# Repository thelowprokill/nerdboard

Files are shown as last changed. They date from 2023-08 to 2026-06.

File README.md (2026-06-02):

# nerdboard

This is my take on a split ergonomic keyboard.
I will add documentation to buid it here soon.

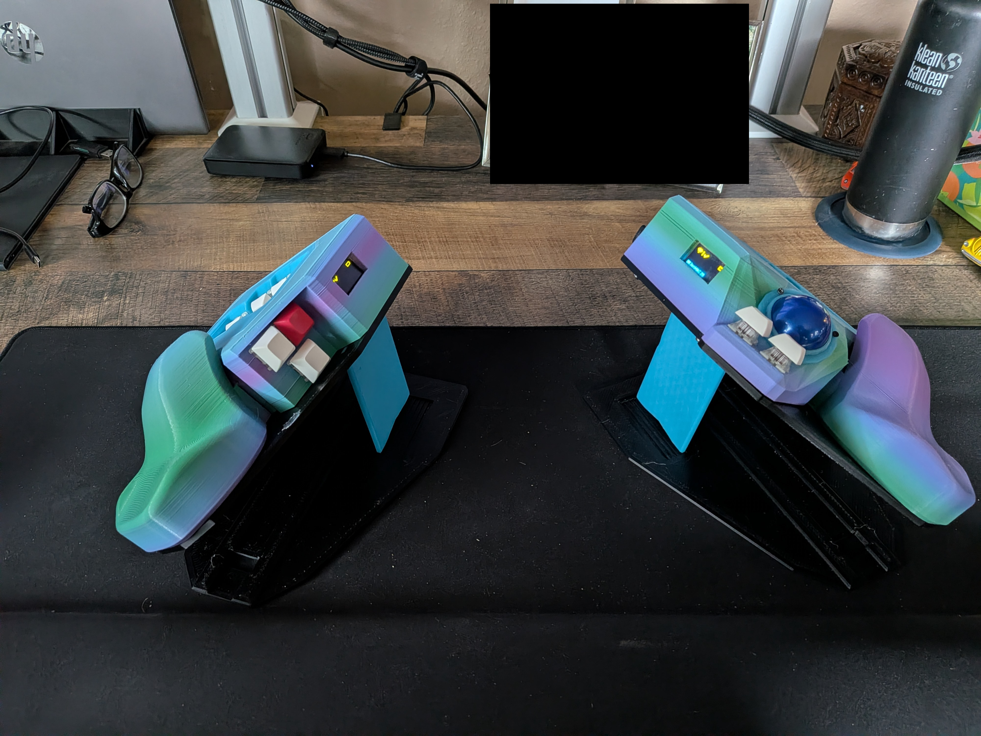
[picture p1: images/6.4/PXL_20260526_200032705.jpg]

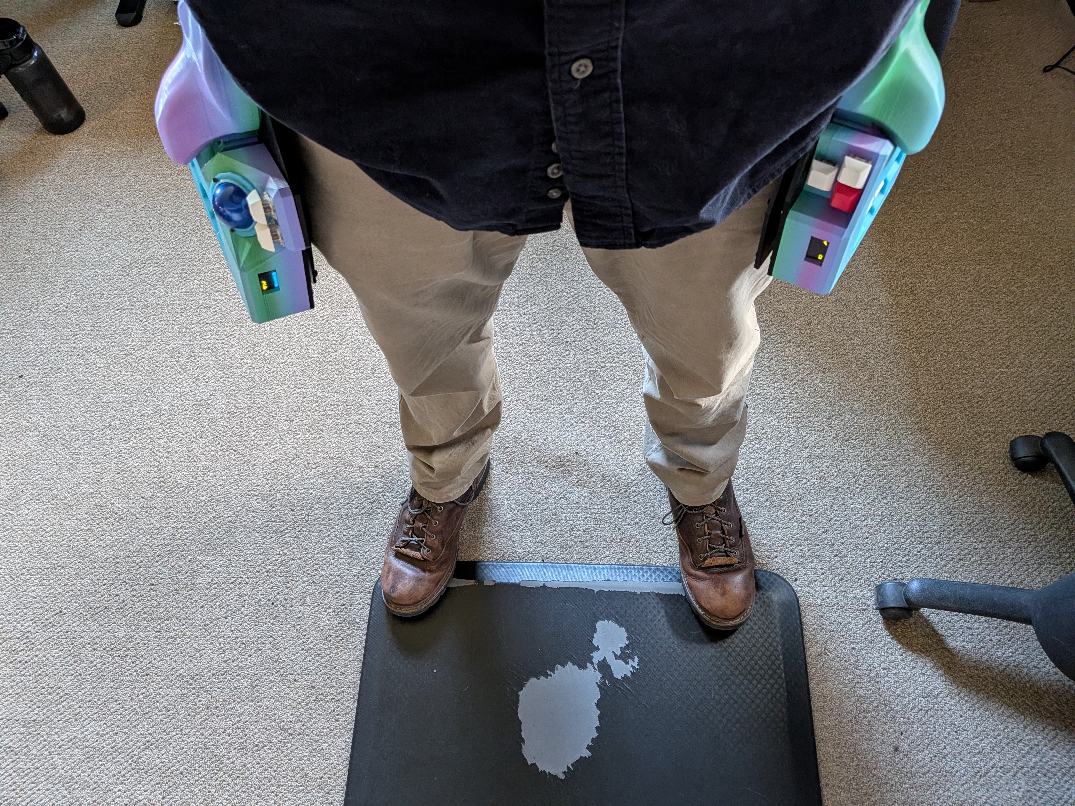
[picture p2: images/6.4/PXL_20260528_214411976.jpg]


# Versions
## 1.0
This version is not my own creation. 
I found it here on [GitHub](https://github.com/Schievel1/dactyl_manuform_r_track).
This is where I started from.

## 2.0
This was my first creation.
I reduced the number of keys from 62 to 46 and tented to make it more ergonomic.
I added holes for the USB cables and reset buttons.
There was a major error on this one where I mirrored the left side to make the right. This made non of the hot swap sockets work.
This one is the most difficult to make.

## 3.0
This is my second creation.
I do not recomend this one.
It is too big.
I didn't realize until I printed it.

## 4.0
This is my third creation.
I do not recomend this one.
I never finished designing it.
Part way through I abandoned it to pursue what became 5.0.

## 5.0
This is my fourth creation.
This one is fine. 
This was the one that reduced the number of keys to 34.
I didn't know what to do with the thumb clusters so they got placed to far away.

## 6.0 
This is my fifth creation.
I really like this one. 
This one reduced the number of keys to 29.
I currently use this one daily at work.
The 29 keys make it so there is no doubt of what key you are using because each finger has a maximum of 3 keys.

### 6.2 
Stability improvement over 6.0.
The palm rest was integrated into the chassis with a slot to improve regitity. 

### 6.3
Comfortability improvement over 6.2
The top part of the palm rest was actually important for comfort and was readded.
Changed the screen to a wider model.

### 6.4 2026-05-25
Switched to wireless keyboard. https://github.com/thelowprokill/zmk-config
Added a removeable keywell to make it easier to assemble and not have doors on the front and rear.
Since it is now wireless there is now a belt hook so the keyboard can be hung from my belt.
I have now been using version 6.something for coming on three years I have been loving it.

## 7 
This is a seperate design for a friend it uses a more standard layout.

## 8
This is a prototype.

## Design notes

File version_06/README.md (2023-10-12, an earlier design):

# Version 6

## Introduction
This is the sixth version of the project and first to de shared with others.
This is a 29 key split keyboard with integrated trackball.

## Hardware
29 diodes
29 switches
29 hot swap sockets
29 keycaps
2  arduino pro micros
2  female usb cables
1  usb c female to micro usb adapter
6  m2x8 screws
14 m3x6 screws
2  m2 thraded inserts
14 m3 thraded inserts
1  PMW 3360 sensor
1  34mm trackball
1  usb c male to usb c male cable
1  usb c male to computer
   jumper cables

## Build
### Print
Print all the parts.
1x left
1x right
1x small_parts

either
1x upper_plate_l
1x upper_plate_r
1x lower_plate_l
1x lower_plate_r
2x kickstand
for the tented version
or
2x plate
for the non-tented version

all the small parts print together.

Remove the supports

### Post proccessing
sand and paint as desired (optional, but recommended)
Install heat inserts into the cases and palm rests.

### Assembly
Diodes:
Solder diodes to the hot swap sockets not the polarity.
One diode per socket.
I try to make the diodes all on the same side of the column.
For one of the rows it will be on the other side.

Sockets:
Insert a socket into each hole in the keyboard.
I recomend using a switch to help hold the socket in place.

Rows:
Start at one end and solder the tail of that diode to the tail of the next diode.
This needs to be done after the diode not before.

Columns:
Use a jumper cable.
Cut off one side.
Use wire strippers to cut the shielding near the uncut side of the jumper cable.
Hold the cut up to one of the sockets I start at the top row.
Mark where it meets the next socket.
Cut the shielding there.
When you get to all the sockets in that column pull the shielding away to reveal about 5mm of the wire underneeth.
Cut the extra wire.
Cut the other side of the jumper cable.
Tin all the joints with the soldering iron.
Solder each wire to the sockets.

USB C link between keyboard halves:
Cut the usb c female cable.
Solder a jumper to VCC(red), GND(black), and Data +-(green white).
To clerify I soldered green and white together to the third jumer.

Insert the usb c female side into the prited case.
I use the hole that is closest to the other side.

USB link from keyboard to computer:
Insert the usb c to micro usb adapter into the other hole in the case.

OLED:
Verify the OLED is working by connecting to the pro micro and plugging the pro micro into a computer.
Remove the film frm the OLED screen.
Attach 4 jumper cables to the OLED note which one goes where.
Gently place the OLED in the hole in the right side of the keyboard.
Hot glue in place.

Pro Micros:
Flash the firmware on the pro micro.
Go to QMK for instructions.
Solder header pins to the pro micro.

Hot glue the pro micro to the table like stand. (Optional but recommended)
Plug in the pro micro to the adapter in the case.
Run wires for the rows or columns that go to the other side of the pro micro accross the keyboard. (Optional but recommended)
Hot glue the four corners of the table.
Place the pro micro table in the case stadleing the wires lain across the keyboard. (It is hard to get them under once the pro micro is glued down)

Matrix:
solder one jumper to each row and one to each column.
Connect to the pro micro using the wiring diagram.

Mouse sensor:
Solder the headers onto the PMW 3360 sensor.
Use two m2x8 screws to attach the sensor to the case.
Connect to the pro micro using the wiring diagram.

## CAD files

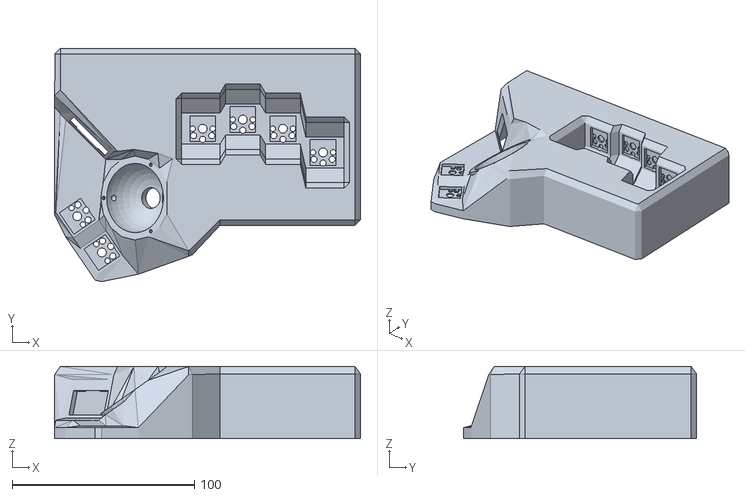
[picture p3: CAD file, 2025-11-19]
lp_01/lp_01_right.stl
167.7 x 127.8 x 39.5

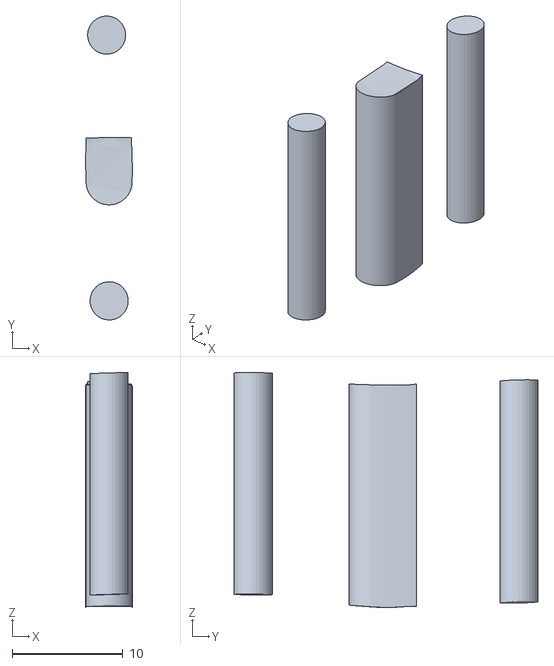
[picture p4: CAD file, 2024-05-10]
parts/sensor_negative.stl
4.21 x 27.5 x 21.2

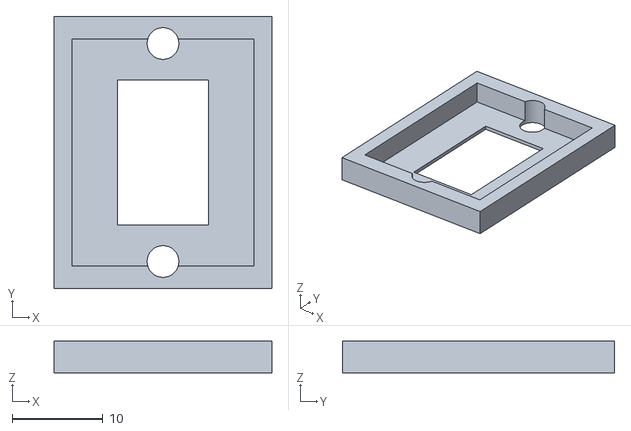
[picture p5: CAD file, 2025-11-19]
trackball_test/trackball_v3_standoff_0.5mm.stl
24.0 x 30.0 x 3.50

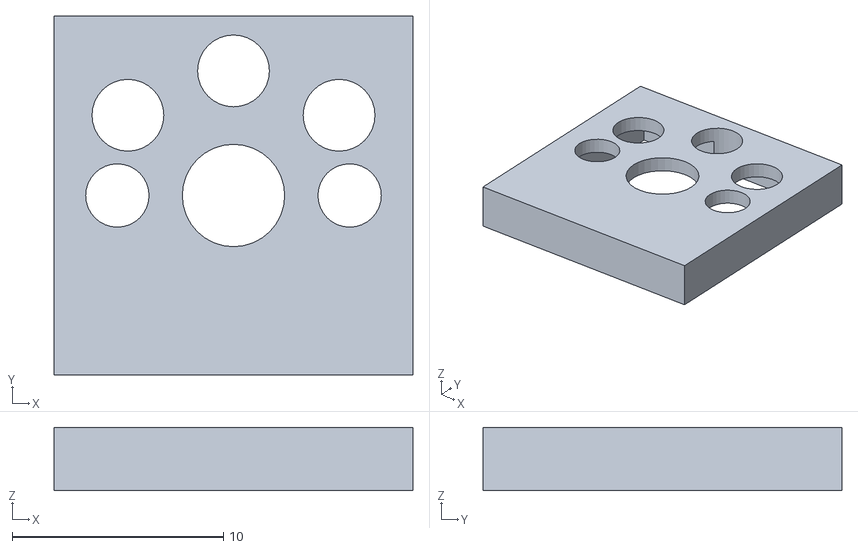
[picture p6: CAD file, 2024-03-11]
lp_01/lp_hotswap.stl
17.0 x 17.0 x 3.00

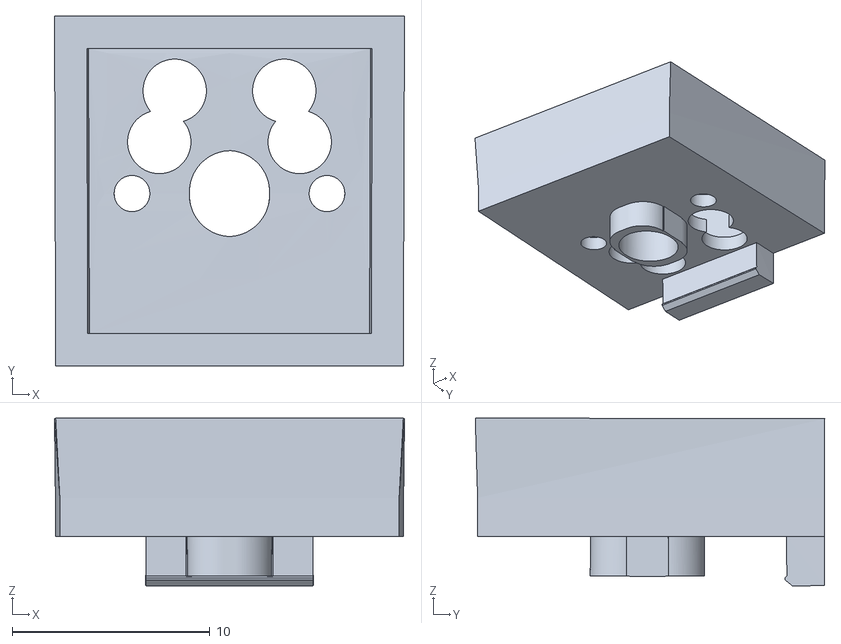
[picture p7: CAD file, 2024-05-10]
parts/hot_swap_socket_reversable_v2_test.stl
17.7 x 17.7 x 8.48

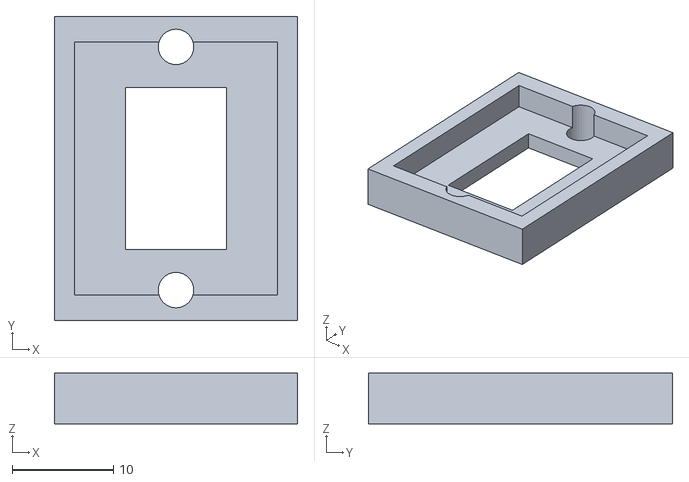
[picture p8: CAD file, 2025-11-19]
trackball_test/trackball_v3_standoff_2mm.stl
24.0 x 30.0 x 5.00

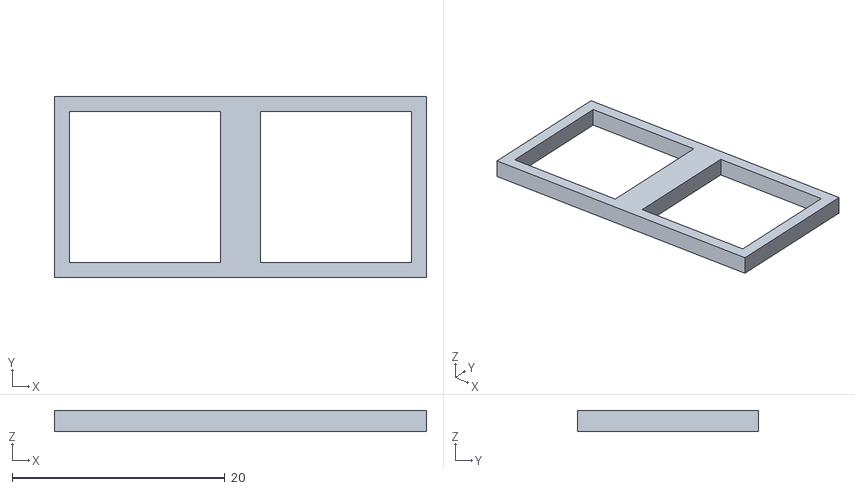
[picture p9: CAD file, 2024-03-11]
lp_01/lp_spacing_test_17mm.stl
35.0 x 17.0 x 2.00

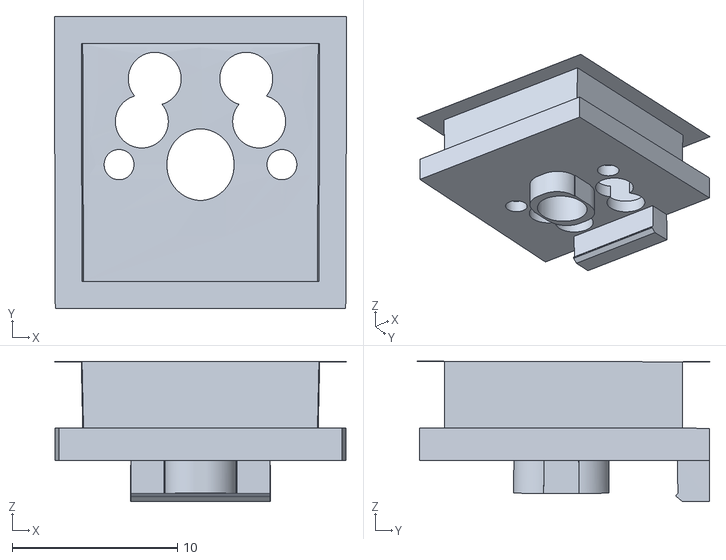
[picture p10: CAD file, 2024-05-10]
parts/hot_swap_socket_reversable_v2.stl
17.7 x 17.7 x 8.48

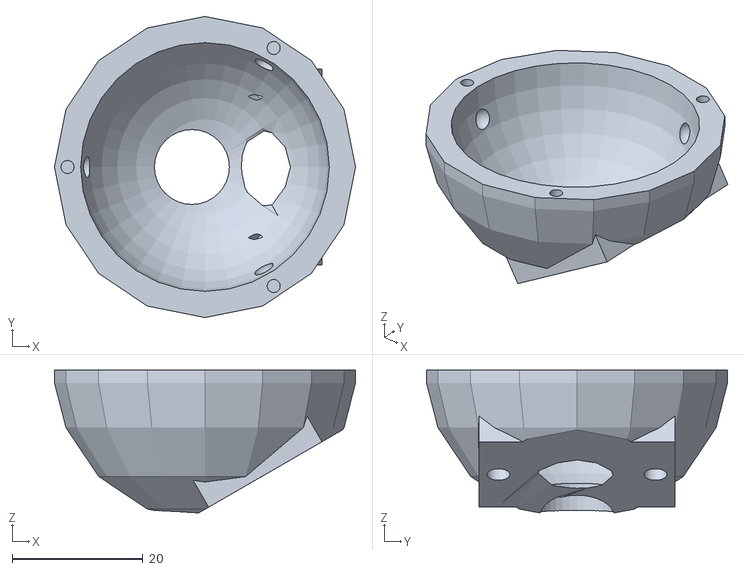
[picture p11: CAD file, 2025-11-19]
trackball_test/trackball_v3.stl
46.0 x 46.0 x 21.8

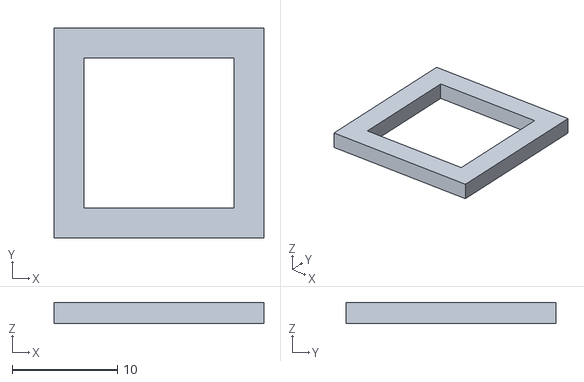
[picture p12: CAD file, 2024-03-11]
lp_01/lp_01_14.3mm.stl
20.0 x 20.0 x 2.00

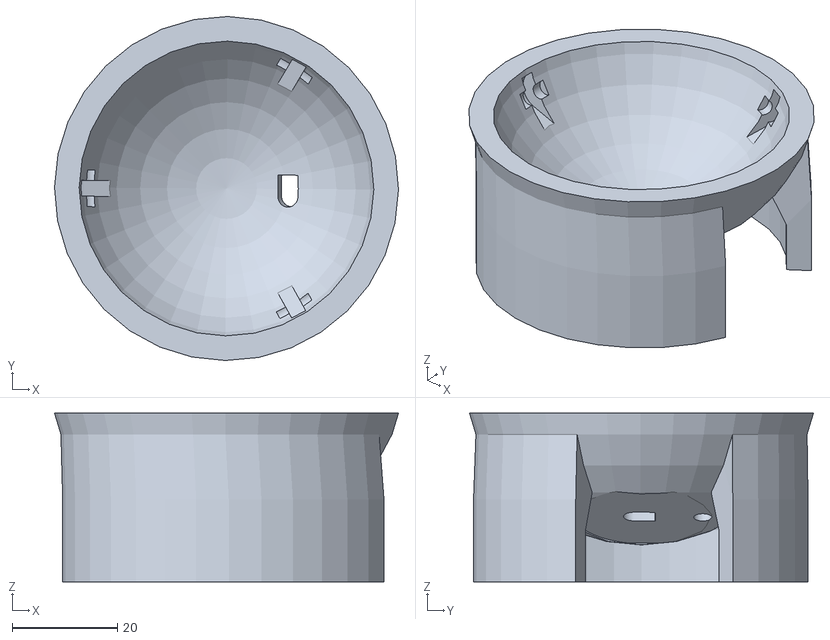
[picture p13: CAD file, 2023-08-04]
parts/large_tracball_test_2_standalone.stl
65.3 x 65.3 x 32.0

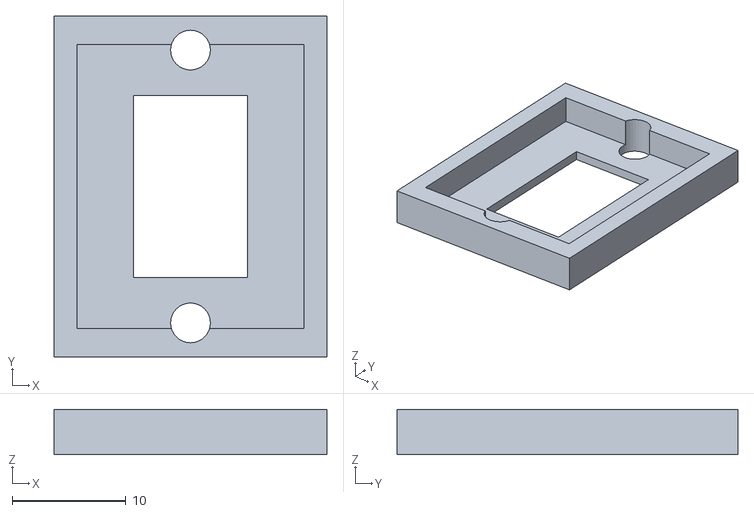
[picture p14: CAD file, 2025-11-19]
trackball_test/trackball_v3_standoff_1mm.stl
24.0 x 30.0 x 4.00

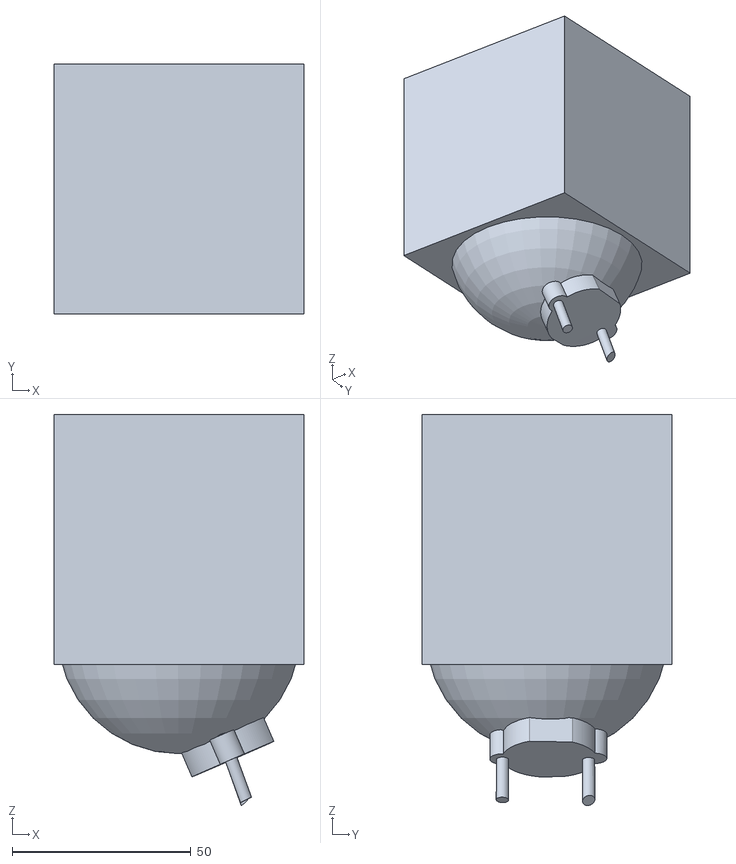
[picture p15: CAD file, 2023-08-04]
parts/large_tracball_test_2.stl
70.0 x 70.0 x 109.5

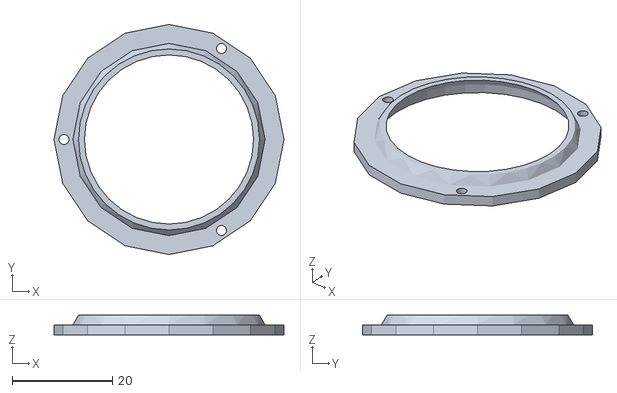
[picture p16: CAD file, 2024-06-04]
trackball_test/trackball_v3_ring_v3.stl
46.0 x 46.0 x 3.91

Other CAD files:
lp_01/lp_hotswap_14.1.stl
lp_01/lp_01_14.5mm.stl
parts/screen_negative.stl
trackball_test/trackball_v3_ring_v2.stl
lp_01/lp_01.stl
lp_01/lp_01_14mm.stl
lp_01/lp_horseshoe.blend
lp_01/lp_horseshoe.stl
lp_01/lp_hotswap.blend
lp_01/lp_spacing_test.stl
parts/hot_swap_socket_reversable.stl
parts/io_negative.stl
parts/io_positive.stl
parts/mouse_bowl.stl
parts/screw_inserts.stl
parts/vertical_test.blend
parts/vertical_test.stl
trackball_test/trackball_test.blend
trackball_test/trackball_test.stl
trackball_test/trackball_v2.blend
trackball_test/trackball_v2.stl
trackball_test/trackball_v2_topper.stl
trackball_test/trackball_v2_topper_v3.stl
trackball_test/trackball_v2_topper_v4.stl
trackball_test/trackball_v2_topper_v5.stl
trackball_test/trackball_v2_topper_v6.stl
trackball_test/trackball_v3.blend
trackball_test/trackball_v3_ring_v1.stl
version_01/controller_holder.stl
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
